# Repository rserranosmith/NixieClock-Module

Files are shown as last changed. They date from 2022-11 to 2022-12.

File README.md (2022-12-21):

# NixieClock-Module
Module that abstracts the nixie tube clock to digital signals

## Signals
The following signals are meant to be multiplexed (one signal should be active at a time). You activate the signal by pulling it high.
N1 - First Nixie Tube
N2  - Second Nixie Tube
SEP - Separator
N3  - Third Nixie Tube
N4  - Fourth Nixie Tube

The following Truth Table shows how to interface with the K155NA1 IC.

| D | C | B | A | Res |
| --- | --- | --- | --- | --- |
| L | L | L | L | 0 |
| L | L | L | H | 1 |
| L | L | H | L | 2 |
| L | L | H | H | 3 |
| L | H | L | L | 4 |
| L | H | L | H | 5 |
| L | H | H | L | 6 |
| L | H | H | H | 7 |
| H | L | L | L | 8 |
| H | L | L | H | 9 |

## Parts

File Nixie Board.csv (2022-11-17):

Qty | Value | Device | Package | Parts | Description | ARROW_PART_NUMBER | ARROW_PRICE-STOCK | DESCRIPTION | HEIGHT | MANUFACTURER_NAME | MANUFACTURER_PART_NUMBER | MOUSER_PART_NUMBER | MOUSER_PRICE-STOCK | MOUSER_TESTING_PART_NUMBER | MOUSER_TESTING_PRICE-STOCK | MPN | POPULARITY | PROD_ID | VALUE
2 |  | CONN_02 | 1X02 | J1, J2 | Multi connection point. Often used as Generic Header-pin footprint for 0.1 inch spaced/style header connections |  |  |  |  |  |  |  |  |  |  | INS-1
4 |  | IN-12BNOHOLE | IN-12-DSUB-NOHOLE | NX1, NX2, NX3, NX4 | IN-12B: medium numeric topview nixie tube |  |  |  |  |  |  |  |  |  |  | IN-12B
1 |  | PINHD-2X7 | 2X07 | JP1 | PIN HEADER |  |  |  |  |  |  |  |  |  |  | 30314-6002HB | 8
15 | 10k | 10KOHM-0603-1/10W-1% | 0603 | R1, R3, R4, R5, R7, R8, R9, R11, R12, R13, R15, R16, R17, R19, R20 | 10kΩ resistor |  |  |  |  |  |  |  |  |  |  | ESR03EZPJ103 |  | RES-00824 | 10k
5 | 1M | 1MOHM-0603-1/4W-5% | 0603 | R2, R6, R10, R14, R18 | 1MΩ resistor |  |  |  |  |  |  |  |  |  |  | ERJ-3EKF1004V |  | RES-07868 | 1M
5 | DXTA92-13 | DXTA92-13 | DXTA9213 | Q1, Q3, Q5, Q7, Q9 | Bipolar Transistors - BJT 1000mW -300Vceo PNP SURFACE MOUNT TRANSISTOR | DXTA92-13 | https://www.arrow.com/en/products/dxta92-13/diodes-incorporated?region=nac | Bipolar Transistors - BJT 1000mW -300Vceo PNP SURFACE MOUNT TRANSISTOR | 1.6mm | Diodes Inc. | DXTA92-13 | 621-DXTA92-13 | https://www.mouser.com/Search/Refine.aspx?Keyword=621-DXTA92-13 |  |  | DXTA92-13
1 | K155ID1 | K155ID1 | DIP16 | U$1 |  |  |  |  |  |  |  |  |  |  |  | K155ID1
1 | NCH8200HV | NCH8200HV | NCH8200HV | U$2 |  |  |  |  |  |  |  |  |  |  |  | NCH8200HV
5 | SXTA42TA | SXTA42TA | SXTA42TA | Q2, Q4, Q6, Q8, Q10 | Diodes Inc SXTA42TA NPN High Voltage Bipolar Transistor, 500 mA, 300 V, 4-Pin SOT-89 | SXTA42TA | https://www.arrow.com/en/products/sxta42ta/diodes-incorporated?region=nac | Diodes Inc SXTA42TA NPN High Voltage Bipolar Transistor, 500 mA, 300 V, 4-Pin SOT-89 | 1.5mm | Diodes Inc. | SXTA42TA | 522-SXTA42TA | https://www.mouser.co.uk/ProductDetail/Diodes-Incorporated/SXTA42TA?qs=GBLSl2AkiruGQsPJmKRQDg%3D%3D |  |  | SXTA42TA

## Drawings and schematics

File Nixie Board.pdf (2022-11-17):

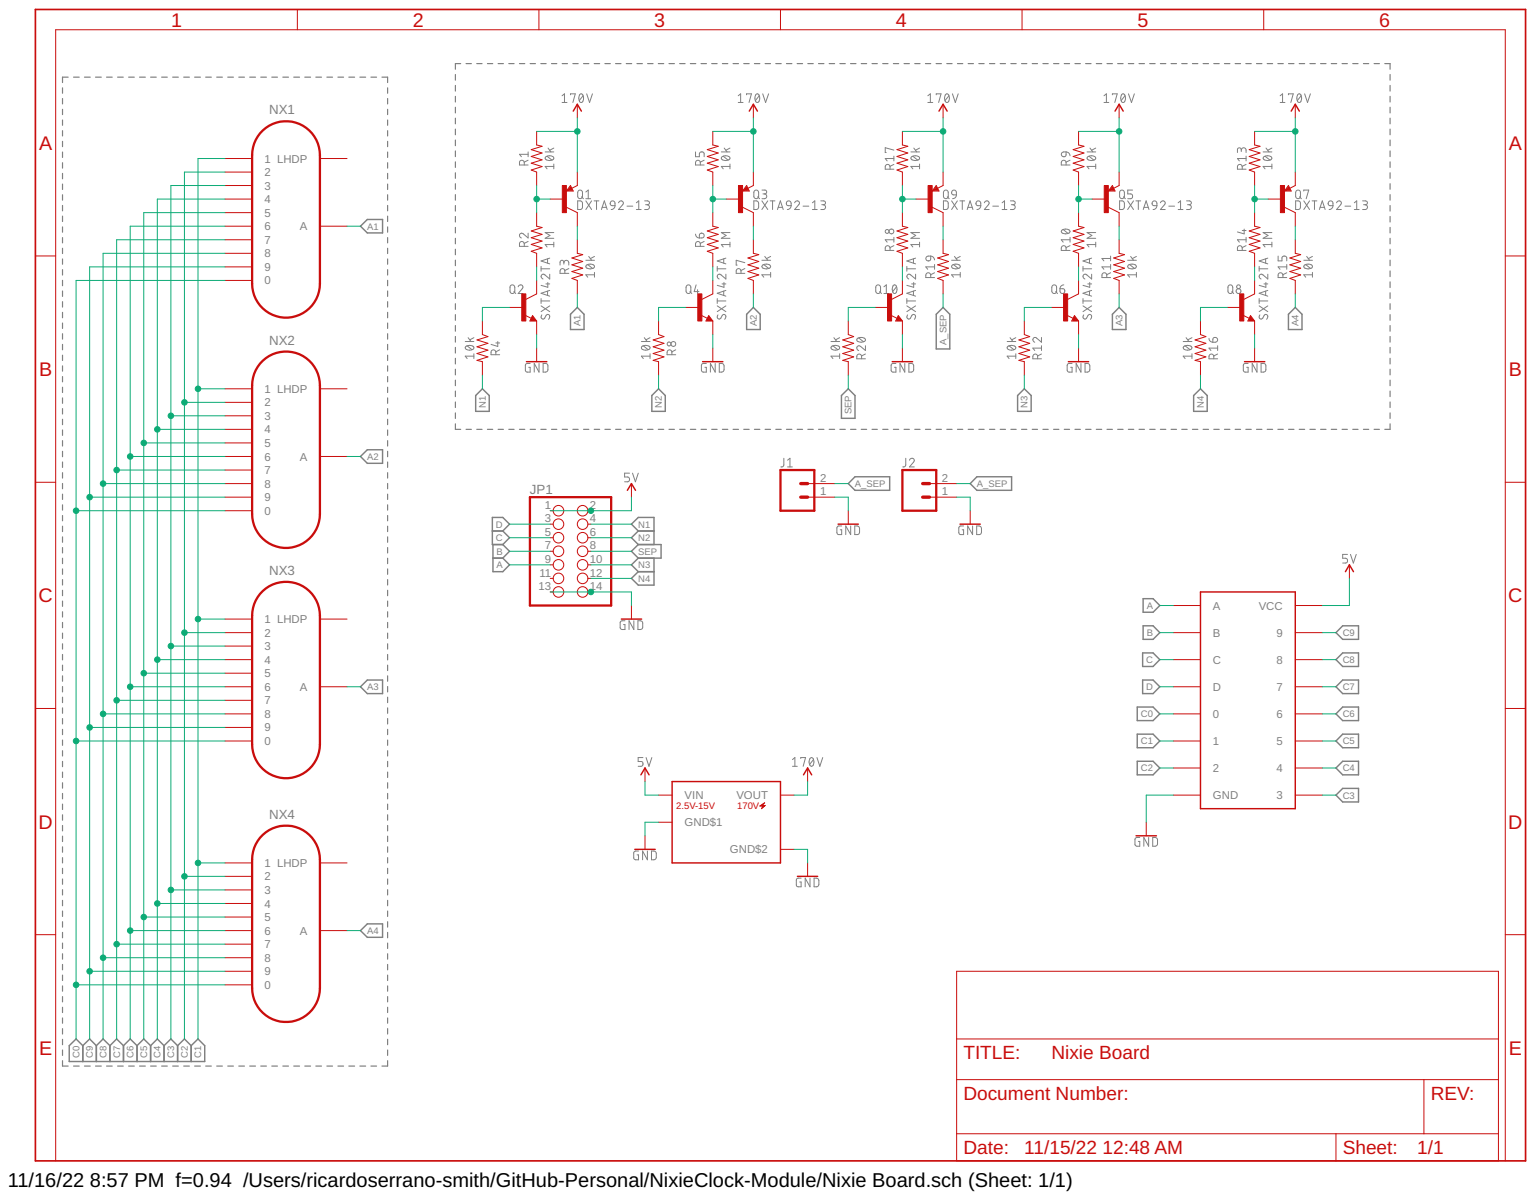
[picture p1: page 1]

VIN GND$1 VOUT GND$2

Document Number: | REV:

Date: 11/15/22 12:48 AM | Sheet: 1/1

11/16/22 8:57 PM f=0.94 /Users/ricardoserrano-smith/GitHub-Personal/NixieClock-Module/Nixie Board.sch (Sheet: 1/1)

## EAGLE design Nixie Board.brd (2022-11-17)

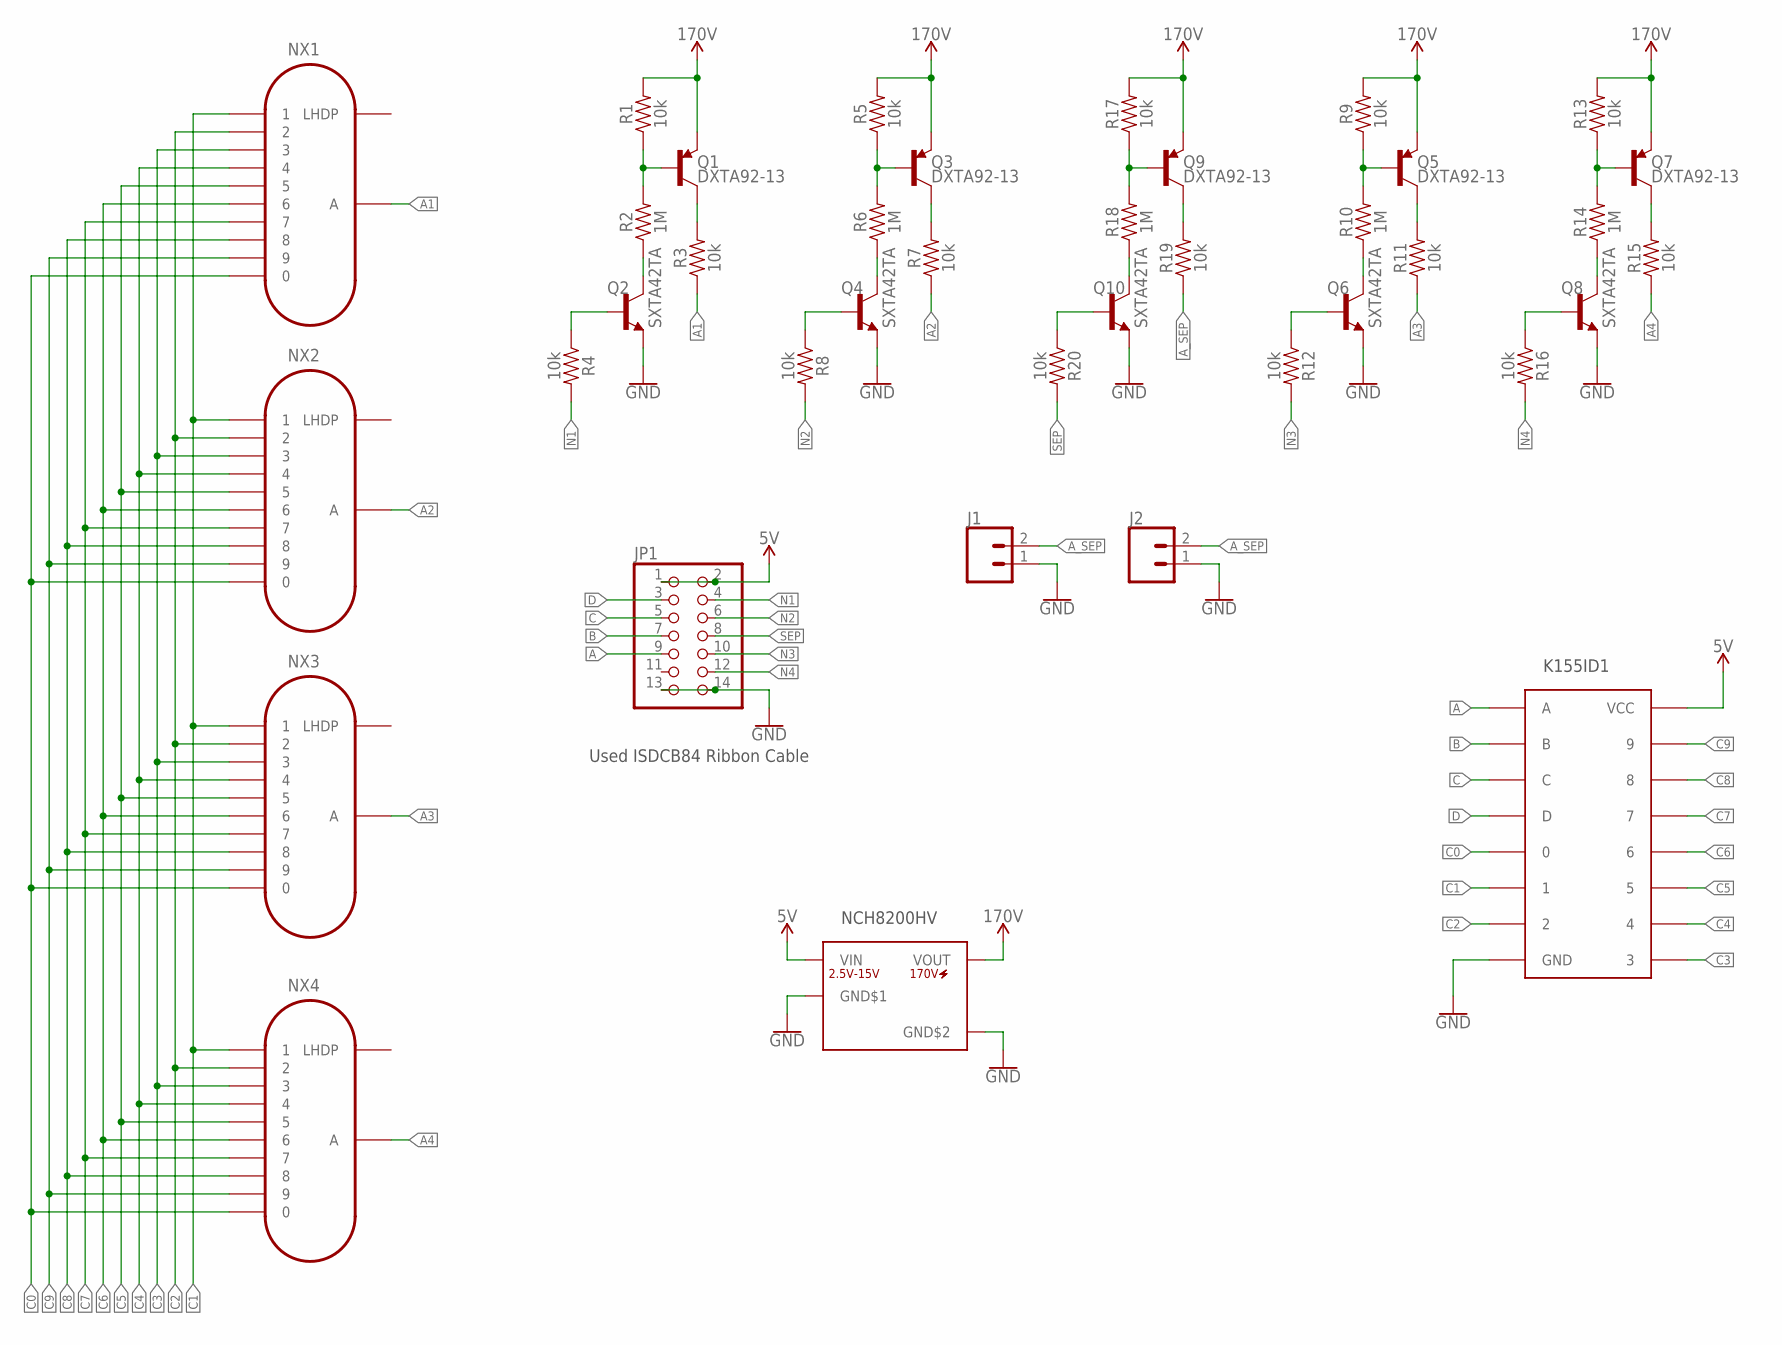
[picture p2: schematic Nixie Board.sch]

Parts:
J1, J2: CONN_02; 1X02; MPN INS-1
JP1: PINHD-2X7; 2X07; MPN 30314-6002HB
NX1, NX2, NX3, NX4: IN-12BNOHOLE; IN-12-DSUB-NOHOLE; MPN IN-12B
Q1, Q3, Q5, Q7, Q9: DXTA92-13; DXTA9213; MPN DXTA92-13
Q2, Q4, Q6, Q8, Q10: SXTA42TA; MPN SXTA42TA
R1, R3, R4, R5, R7, R8, R9, R11, R12, R13, R15, R16, R17, R19, R20: 10k; 0603; MPN ESR03EZPJ103
R2, R6, R10, R14, R18: 1M; 0603; MPN ERJ-3EKF1004V
U$1: K155ID1; DIP16; MPN K155ID1
U$2: NCH8200HV; MPN NCH8200HV

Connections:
5V: JP1.1, JP1.2, U$1.5 (VCC), U$2.P$1 (VIN)
A: JP1.9, U$1.3 (A)
A1: NX1.A, R3.1
A2: NX2.A, R7.1
A3: NX3.A, R11.1
A4: NX4.A, R15.1
A_SEP: J1.2, J2.2, R19.1
B: JP1.7, U$1.6 (B)
C: JP1.5, U$1.7 (C)
C0: NX1.0, NX2.0, NX3.0, NX4.0, U$1.16 (0)
C1: NX1.1, NX2.1, NX3.1, NX4.1, U$1.15 (1)
C2: NX1.2, NX2.2, NX3.2, NX4.2, U$1.8 (2)
C3: NX1.3, NX2.3, NX3.3, NX4.3, U$1.9 (3)
C4: NX1.4, NX2.4, NX3.4, NX4.4, U$1.13 (4)
C5: NX1.5, NX2.5, NX3.5, NX4.5, U$1.14 (5)
C6: NX1.6, NX2.6, NX3.6, NX4.6, U$1.11 (6)
C7: NX1.7, NX2.7, NX3.7, NX4.7, U$1.10 (7)
C8: NX1.8, NX2.8, NX3.8, NX4.8, U$1.1 (8)
C9: NX1.9, NX2.9, NX3.9, NX4.9, U$1.2 (9)
D: JP1.3, U$1.4 (D)
GND: J1.1, J2.1, JP1.13, JP1.14, Q2.3 (E), Q4.3 (E), Q6.3 (E), Q8.3 (E), Q10.3 (E), U$1.12 (GND), U$2.P$2 (GND$1), U$2.P$3 (GND$2)
N1: JP1.4, R4.2
N2: JP1.6, R8.2
N3: JP1.10, R12.2
N4: JP1.12, R16.2
unnamed: Q1.1 (B), R1.1, R2.2
unnamed: Q1.2 (C), R3.2
unnamed: Q2.2 (C), R2.1
unnamed: Q2.1 (B), R4.1
unnamed: Q3.1 (B), R5.1, R6.2
unnamed: Q3.2 (C), R7.2
unnamed: Q4.2 (C), R6.1
unnamed: Q4.1 (B), R8.1
unnamed: Q5.1 (B), R9.1, R10.2
unnamed: Q5.2 (C), R11.2
unnamed: Q6.2 (C), R10.1
unnamed: Q6.1 (B), R12.1
unnamed: Q7.1 (B), R13.1, R14.2
unnamed: Q7.2 (C), R15.2
unnamed: Q8.2 (C), R14.1
unnamed: Q8.1 (B), R16.1
unnamed: Q9.1 (B), R17.1, R18.2
unnamed: Q9.2 (C), R19.2
unnamed: Q10.2 (C), R18.1
unnamed: Q10.1 (B), R20.1
SEP: JP1.8, R20.2
VCC_1: Q1.3 (E), Q3.3 (E), Q5.3 (E), Q7.3 (E), Q9.3 (E), R1.2, R5.2, R9.2, R13.2, R17.2, U$2.P$4 (VOUT)

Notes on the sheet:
K155ID1
NCH8200HV
Used ISDCB84 Ribbon Cable

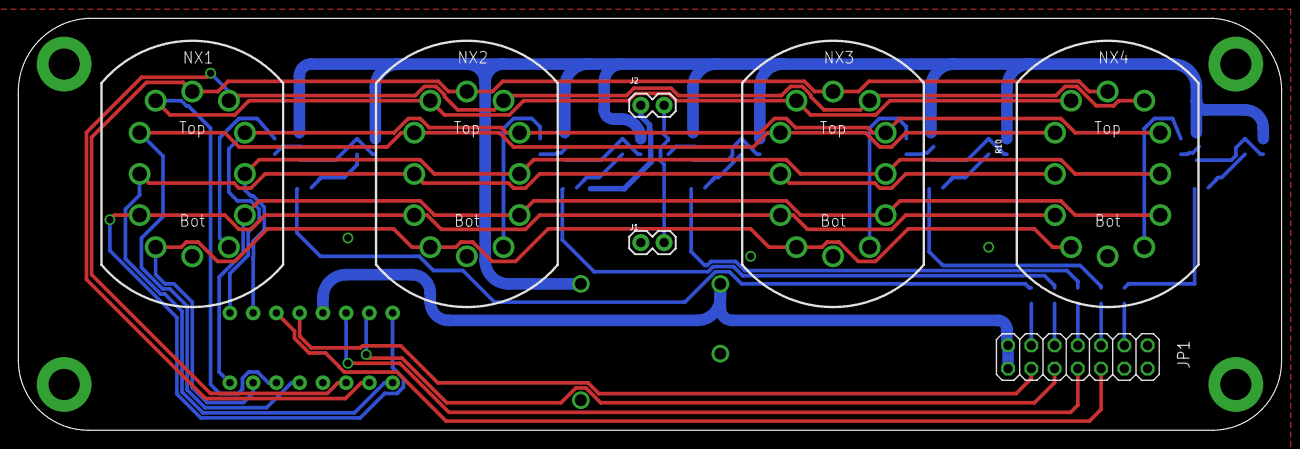
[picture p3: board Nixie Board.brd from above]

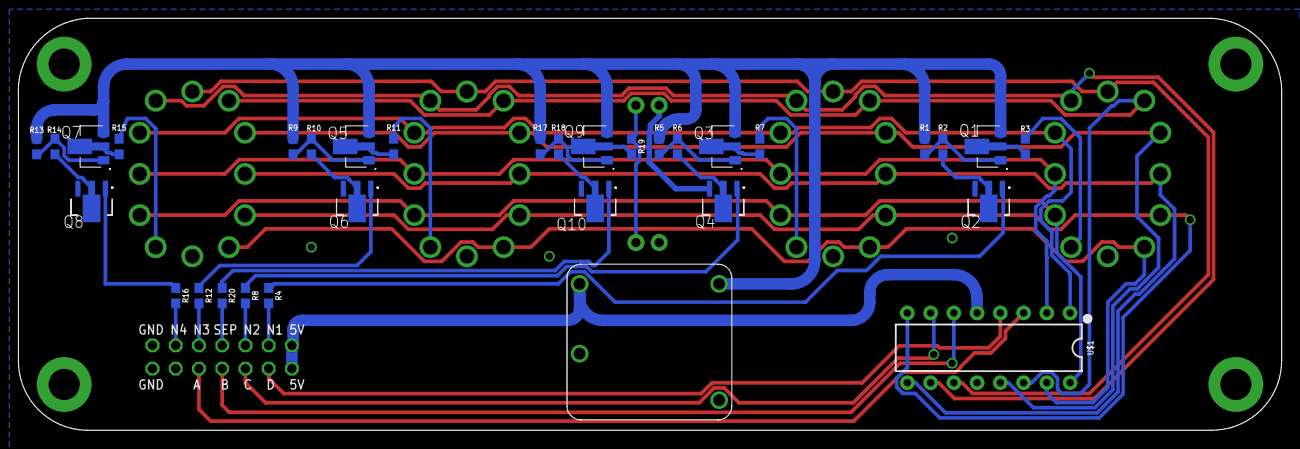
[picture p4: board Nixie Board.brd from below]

Board: 2 copper layers, 138.0 x 45.0 mm, 39 parts (32 on the bottom side), 47 nets.

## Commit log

2022-11-17 feat: first version of Nixie Clock - Ordered via JLCPCB
    [Nixie Board.brd, Nixie Board.sch]
2022-11-17 chore: created PDF of circuit schematic
2022-11-17 chore: added bom and MPN to components
    [Nixie Board.brd, Nixie Board.csv, Nixie Board.sch]

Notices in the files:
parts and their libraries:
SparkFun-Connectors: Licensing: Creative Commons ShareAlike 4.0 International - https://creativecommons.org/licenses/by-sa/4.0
